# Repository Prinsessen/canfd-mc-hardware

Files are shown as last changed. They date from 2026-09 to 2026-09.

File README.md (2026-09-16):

# CANFD-MC — a minimal CAN board for a motorcycle

A 55 × 32 mm, 4-layer board that replaces the LilyGO T-2CANFD in the
[indian-thunderstroke-canbus](https://github.com/Prinsessen/indian-thunderstroke-canbus)
project: ESP32-S3-WROOM-1U + MCP2518FD + TCAN332G, fed from the bike's
permanent 12 V through an LM5164 buck. Same pin map as the LilyGO board, so the
firmware runs unchanged (`sniffer-t2can` environment).

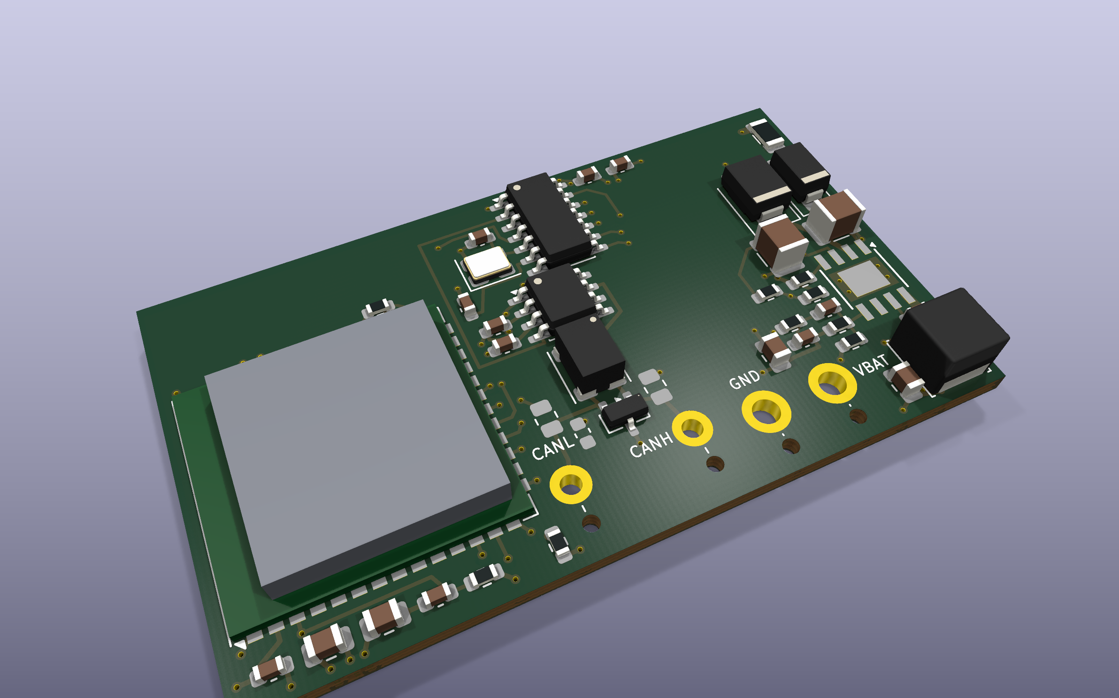
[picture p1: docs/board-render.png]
CANFD-MC rev 1.0, top


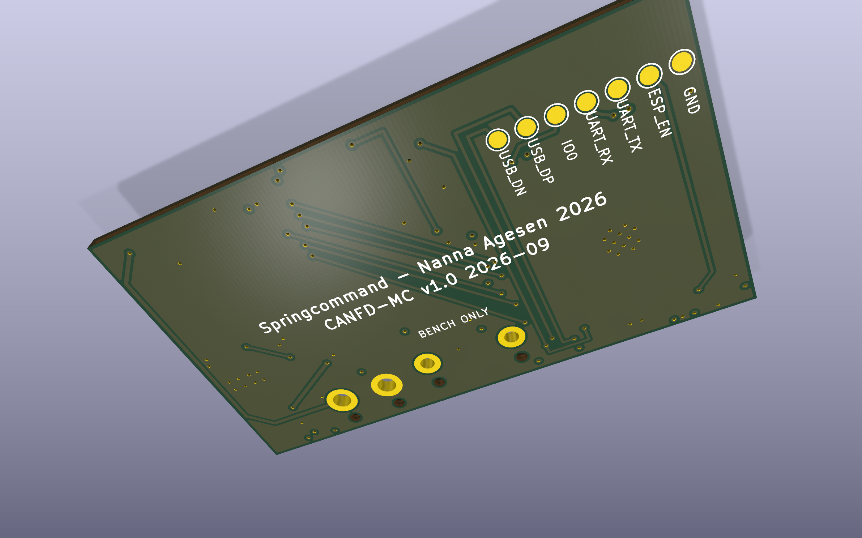
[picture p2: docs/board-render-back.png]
CANFD-MC rev 1.0, back: flash pads, test points, silkscreen


What it drops from the LilyGO board, on purpose: the isolated transceiver (one
machine, one ground — the isolation was bridged the moment it was wired in, and
its DC-DC was three quarters of the sleep current), the USB connector, the screw
terminals, the second CAN channel, and the 120 Ω termination (the bike's bus is
already terminated; a third resistor is a stub). What it adds: a 6–40 V input
that survives load dump, four solder pads with strain-relief holes instead of
connectors, and a ~10 µA regulator so the board can live on the battery.

## Layout

```
canfd-mc.kicad_pro / .kicad_sch / .kicad_pcb   KiCad 10 project — placed, routed, DRC clean
canfd_local.pretty/                            three project footprints (solder pads with relief
                                               holes, Murata DLW43SH with Murata's pin numbering)
production/                                    what JLCPCB was sent: Gerber zip, BOM, CPL
docs/design-document.html                      the full design document: BOM, net list, the
                                               LM5164 calculation, layout rules, checklist
docs/BUILD-NOTES.md                            build, ordering and bring-up notes
docs/WIRING-PARTS.md                           antenna and service-connector cable to order
```

## Connections

Four wires from the service connector, soldered to plated pads along the bottom
edge — **CANL · CANH · GND · VBAT**. Each pad has an unplated 1.2 mm hole 3 mm
inboard: thread the wire up through the hole and down into the pad, so the
board takes the strain instead of the solder joint. No shield pad: the bus
shield is grounded at the ECM.

Flashing pads on the back, 2.54 mm pitch — **GND · EN · TX · RX · IO0 · USB_D+ · USB_D−**.
First flash goes over the ESP32-S3's native USB (a cut USB cable on D+/D−/GND;
the board is powered from 12 V, not from USB). After that, OTA.

## Power input

| | |
|---|---|
| Input | 6–40 V (LM5164 is rated to 100 V; the TVS clamps load dump at ~39 V) |
| UVLO | on at 7.0 V, off at 6.5 V |
| Output | 3.3 V, 300 kHz, 1 A rating (real load < 0.5 A) |
| Protection | 1 A fuse, series Schottky (reverse polarity), SMBJ24CA |

The buck was calculated from the LM5164 datasheet equations and confirmed with
TI's WEBENCH: RON, inductor and bootstrap capacitor came out identical.

## Status

Rev 1.0. Ordered from JLCPCB in September 2026 (5 boards, assembled). Reviewed
([docs/REVIEW-rev1.0.md](docs/REVIEW-rev1.0.md)): net list confirmed against the
datasheets, three notes for rev 1.1. Not yet tested on
hardware — this is a first revision, and the bring-up checklist in the design
document is the plan for finding out what it got wrong.

Things a second revision might change are tracked in the design document's
open-points table.

## Licence

MIT, like the firmware. Design and silkscreen: Springcommand — Nanna Agesen 2026.

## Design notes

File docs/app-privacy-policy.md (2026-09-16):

# Springfield app — privacy policy

*Last updated 16 September 2026*

The Springfield app (package `dk.agesen.springfield`) is an instrument display
for Indian Thunder Stroke motorcycles fitted with the CANFD-MC interface. It is
published by Nanna Agesen, Denmark.

## What the app collects

**Nothing leaves your phone.** The app has no server, no account, no analytics,
no advertising and no crash reporting. It does not connect to the internet.

Data the app handles stays on the device:

- **Motorcycle data** (speed, revs, fuel, tyre pressures, fault codes and so on)
  is received over Bluetooth Low Energy from the interface on the bike and shown
  on screen. Some of it — tyre readings, the trip meter, the service interval —
  is stored on the phone so the app can show trends. It is never transmitted
  anywhere.
- **Heated-clothing control** (Keis) is sent over Bluetooth to your own garment
  controller.

## Permissions

| Permission | Why |
|---|---|
| Bluetooth (scan, connect) | To find and talk to the interface on the bike and to the heated clothing. The scan is declared *never for location*: the app does not derive, store or use your position |
| Foreground service, notifications | To keep the Bluetooth link alive while the screen is off, with a persistent notification while it runs |
| Vibrate | A short tick on a gear change and at the redline |

The app does not request location, camera, microphone, contacts, storage or any
other permission.

## Data sharing

None. No data is shared with the publisher or any third party.

## Deleting your data

Uninstalling the app removes everything it stored. There is nothing to delete
anywhere else.

## Contact

Nanna Agesen — via the GitHub project
[Prinsessen/indian-thunderstroke-canbus](https://github.com/Prinsessen/indian-thunderstroke-canbus).

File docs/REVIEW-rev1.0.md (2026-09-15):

# Review of rev 1.0 — 2026-09-15

A second pair of eyes on the design before the boards arrive, written on the
openHAB server with the firmware repository open beside it. Two parts: what was
checked mechanically, and an opinion on the three design decisions.

## 1. Net list, checked against the datasheets

Checked from `canfd-mc.kicad_pcb` — the pad-to-net assignment that was actually
fabricated — against the firmware's pin map and against Espressif's WROOM-1U
and TI's LM5164 datasheets, not against the design document.

**Everything matches.**

- ESP32 ↔ MCP2518FD is the firmware's map exactly: SCLK 12, MOSI 11, MISO 13,
  CS 10, INT 8. IO9/IO3 are the controller's INT0/INT1 outputs with no pull-ups,
  as on the LilyGO. MCP_INT has a 10 k pull-up, and GPIO8 is RTC-capable, so
  the ext0 wake in `sleep.cpp` works unchanged.
- All 41 module pins agree with the WROOM-1U datasheet, including USB_D− on 13,
  USB_D+ on 14, **RXD0 on 36 and TXD0 on 37** (checked twice; the datasheet
  says pin 36 is U0RXD/GPIO44 and pin 37 is U0TXD/GPIO43).
- LM5164 pin for pin: GND · VIN · EN/UVLO · RON · FB · PGOOD · BST · SW, EP to
  GND. Enable thresholds 1.5 V / 1.4 V and FB reference 1.2 V as used in §4.5.
  The type-3 ripple network is wired as the datasheet draws it: RA from SW to
  the injection node, CA from that node to VOUT, CB from that node to FB.
- Input chain VBAT → F1 → D1 (anode towards the fuse, cathode towards the buck,
  so the right way round) → D2 → C1/C2 → U3.
- Bus front end: TCAN332G → L1 (windings 1–2 and 4–3, Murata's numbering) →
  PESD2CAN on the bus side → pads. RT1/RT2/CT1 unpopulated and marked.
- The strain-relief holes sit between pad and board edge, as §6.0 describes.

## 2. Three things for rev 1.1 — none of them blocks bring-up

1. **The PSRAM open point is cheaper than §2 says.** The firmware is built for
   the PlatformIO board `esp32-s3-devkitc-1`, which is the *"N8, No PSRAM"*
   definition: partition table `default_8MB.csv`, no `BOARD_HAS_PSRAM`. The
   PSRAM is never initialised and only 8 MB of the flash is used. So the
   85 °C variants — **N16R2 or plain N8** — need **no firmware change at all**.
   Open point 7 can be closed as a purchasing decision; I would order rev 1.1
   with an 85 °C module without waiting for the temperature measurement.
2. **Leftover net `ACC_SENSE` on IO1 (pin 39).** One pad, no track, so DRC has
   nothing to complain about. Harmless — IO1 is not a strapping pin — but §4.1
   says IO1 is NC. Delete the label.
3. **BOM comment `22uF 10V`** on C3/C4/C12/C13. LCSC C45783 is Samsung
   CL21A226MAQNNNE: 22 µF **25 V** X5R 0805. The part number drives the order,
   so only the text is wrong.

The firmware side of the §9 checklist — the comment in `can_hal_mcp.cpp` about
Longan_CANFD assuming 40 MHz — is fixed in the firmware repository.

## 3. Opinion on the three decisions

**Yes: the minimal board is the better solution, and each of the three choices
is right for this job.** This is no longer a development board; it is a
permanently installed, single-purpose device on a vehicle that vibrates and
lives off a battery. Those are different requirements from the ones the LilyGO
was built for.

**One channel.** Obvious. The firmware has only ever used CAN A. Channel B was
dead weight, board area and current.

**Solder pads instead of screw terminals.** Right, on a motorcycle. Screw
terminals work loose under vibration, and a solder joint on a vehicle fails at
the root of the wire, not in the solder — which is exactly what the
strain-relief holes address. What you give up is that swapping a board becomes
a soldering job. With five boards and a small service loop in the wires, that
does not matter.

**No galvanic isolation.** Also right, for the reason §1 of the design document
gives: supply and bus come from the same service connector with the same
ground, so the isolation was bridged the moment it was wired in, and its DC/DC
cost three quarters of the sleep current. Isolation protects against ground
offsets between two systems. Here there is one system.

Where the price of those choices actually lies:

- **The one-ground rule has to hold all the way.** The single situation in
  which isolation would have saved something is USB ground to a mains-powered
  PC while the board is on the bike. Bring-up over the USB pads should happen
  with the board off the bike, or with a laptop on battery. Worth a line in
  BUILD-NOTES.
- **The starter motor.** UVLO releases at 6.5 V. A cold crank can dip below
  that. The consequence is a reboot at every start: lost seconds and a BLE
  reconnect. The design document says the wake path tolerates it, and it does.
  But measure the dip during cranking before rev 1.1 is frozen. If it is a
  problem, the answer is a regulator with a lower minimum input, not a bigger
  capacitor.
- **Sleep current.** Without the isolation module, 7–9 mA is expected. That is
  about 0.2 Ah a day — a couple of months of rest on a healthy battery, fine
  for a bike that is ridden. Going lower means the transceiver (the 332G has no
  standby pin) and the MCP2518FD in Normal mode, and that needs a different
  wake strategy. Not now.
- **Temperature.** See item 1 above: an 85 °C module costs nothing in firmware.
- **First-revision risks** are the two the design document already caught: the
  choke footprint with Murata's numbering, and the crystal load capacitors.
  Both are the classic "reads zero frames" faults, and both are handled.

So: not "good enough", but the right design. What is left, only the bench can
answer.

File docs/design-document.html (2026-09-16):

Design document · rev 1.0 · 2026-09-15 · board routed, DRC clean, ordered

# CANFD-MC Adapter

A minimal board for the Indian Springfield bus: ESP32-S3-WROOM-1U + MCP2518FD, soldered wires, no USB connector, no isolation, no termination. The firmware from Prinsessen/indian-thunderstroke-canbus (environment sniffer-t2can) runs unchanged.

MCU module

ESP32-S3-WROOM-1U-N16R8

CAN controller

MCP2518FD · SPI · 40 MHz

Transceiver

TCAN332G · 3.3 V

Supply

6–40 V in · LM5164 → 3.3 V

Bus

J1939 · 250 kbit/s · classic

Board

55 × 32 mm · 4 layers

Pin numbers were looked up in LilyGO's schematic T-2Can-Fd_V1.0.pdf, Espressif's WROOM-1 datasheet and TI SNVSAU4D — not from memory. The buck values in §4.5 were calculated from the datasheet equations and confirmed in WEBENCH.

## 1Block diagram

One ground throughout. Supply and bus come from the same service connector on the bike, so LilyGO's isolated TD501MCANFD module (and its internal DC/DC, which was three quarters of the 17 mA sleep current) is gone. The only parts that are genuinely redrawn compared with LilyGO are the power supply and the bus front end; the MCP2518FD section is a 1:1 copy.

## 2Module choices

ESP32-S3-WROOM-1U-N16R8 — the same module as the T-2CANFD, so platformio.ini (esp32-s3-devkitc-1, 16 MB flash / 8 MB OPI PSRAM) and the partition table are untouched. The module has a U.FL connector instead of a PCB antenna, which is the right choice on a motorcycle anyway.

Temperature: the N16R8 is only rated −40…+65 °C ambient

The 8 MB octal PSRAM is the limit. Under a seat in the sun, 65 °C is not much margin. Review finding (2026-09-15): the firmware is built for the PlatformIO board esp32-s3-devkitc-1, which is the "N8, no PSRAM" definition — the PSRAM is never initialised and only 8 MB of flash is used. So the +85 °C variants N8 or N16R2 need no firmware change. Rev 1.0 was built with the N16R8 before this was noticed; keep those boards out of the hottest spots. Rev 1.1: order an 85 °C module. Same footprint.

MCP2518FD in SOIC-14, 3.3 V, 40 MHz crystal — exactly as LilyGO. The firmware runs the controller in Normal20B (classic CAN + 29-bit IDs) or ListenOnly; CAN FD is not used, but the chip is the one the code and ACAN2517FD know.

TCAN332G — 3.3 V transceiver, SOIC-8, −40…+125 °C, no extra pins to wire. Listen-only is handled in the MCP2518FD, so the transceiver's silent pin (TCAN337G) is unnecessary. Drop-in alternatives with the same base pinout: TCAN337G, SN65HVD230.

LM5164 — 100 V, 1 A synchronous buck with ~10 µA quiescent current. Survives load dump with the TVS as the only protection, and the quiescent current matters when the board hangs permanently on the battery.

## 3BOM

All passives SMD 0603 unless stated. Capacitors X7R (C0G where stated), −55…+125 °C. No electrolytics. LCSC numbers are the parts JLCPCB had in stock on 2026-09-15.

Ref | Part | Value / type | Package | LCSC | Note
Active
U1 | ESP32-S3-WROOM-1U-N16R8 | 16 MB / 8 MB OPI · 65 °C | Module 18 × 19.2 mm | C3013946 | Rev 1.0 as built. Rev 1.1: N8 or N16R2 (85 °C), see §2
U2 | MCP2518FDT-E/SL | CAN FD controller | SOIC-14 | C626758 | As LilyGO
U3 | LM5164DDAR | 100 V / 1 A buck | SO PowerPAD-8 | C477928 | EP to GND plane
U4 | TCAN332GDR | 3.3 V CAN transceiver | SOIC-8 | C191010 | Pins 5 and 8 NC
Oscillator
X1 | Crystal YXC X322540MPB4SI | 40.000 MHz ±10 ppm · CL 15 pF | 3225 | C9010 | −40…+85 °C — the module is the limit anyway. See §4.3
C10, C11 | Load capacitors | 22 pF C0G | 0603 | C1653 | 2·(15 − 3) pF. LilyGO uses 12 pF for a ~10 pF crystal — not the same crystal
Supply — input
P1, P2 | Solder pad VBAT / GND | Ø2.0 mm plated | — | — | + strain-relief hole, §6.0
F1 | Fuse 1 A slow | 63 V | 1206 | C151135 | Littelfuse 0466001.NRHF
D1 | Schottky, series (reverse polarity) | SS36 · 60 V / 3 A | SMA | C16015 | ~0.35 V drop, ~40 mW at 100 mA
D2 | TVS, bidirectional | SMBJ24CA | SMB | C83268 | After D1. Clamps load dump < 40 V. Bidirectional = cannot be placed backwards
C1, C2 | Input capacitor | 4.7 µF 100 V X7S | 1210 | C385986 | As close as possible to U3 VIN/GND
Supply — LM5164 (calculated in §4.5)
L2 | Inductor, shielded | 22 µH · Changjiang FNR5040S220MT | 5 × 5 × 4 mm | C167971 | Isat ~1.7 A — plenty for a real load < 0.5 A
C3, C4 | Output capacitor | 22 µF 25 V X5R | 0805 | C45783
C5 | Bootstrap | 2.2 nF 50 V X7R | 0603 | C1604 | Datasheet requirement
R1 | RRON | 27.4 kΩ 1 % | 0603 | C22964 | → 300 kHz
R2 | RFB1 (VOUT → FB) | 100 kΩ 1 % | 0603 | C25803
R3 | RFB2 (FB → GND) | 57.6 kΩ 1 % | 0603 | C23082 | → 3.28 V
R4 | RA (SW → CA) | 150 kΩ | 0603 | C22807 | Type-3 ripple injection
C6 | CA | 2.2 nF X7R | 0603 | C1604 | Type-3 ripple injection
C7 | CB | 270 pF C0G | 0603 | C1657 | Type-3 ripple injection
R5 | RUV1 (VIN → EN) | 365 kΩ 1 % | 0603 | C23031 | UVLO on 7.0 V / off 6.5 V
R6 | RUV2 (EN → GND) | 100 kΩ 1 % | 0603 | C25803
Decoupling 3V3
C12, C13 | ESP32 bulk | 22 µF 25 V X5R | 0805 | C45783 | At U1 pin 2 — as LilyGO C4/C5
C14 | ESP32 HF | 100 nF | 0603 | C14663 | At U1 pin 2
C15, C16 | MCP2518FD | 10 µF + 100 nF | 0603 | C19702 · C14663 | At U2 pin 14 — as LilyGO C13/C12
C17, C18 | TCAN332G | 4.7 µF + 100 nF | 0603 | C19666 · C14663 | At U4 pin 3
C19 | EN delay | 1 µF | 0603 | C15849 | U1 EN → GND (LilyGO C8)
R7, R8, R9 | Pull-up EN · IO0 · INT | 10 kΩ | 0603 | C25804 | To 3V3
Bus front end
P3, P4 | Solder pad CANH / CANL | Ø1.5 mm plated | — | — | + strain-relief hole, §6.0
L1 | Common-mode choke, CAN | Murata DLW43SH101XK2L | 4532 | C123085 | AEC-Q200. Pins 1/4 at one end, 2/3 at the other — project footprint. Does not tolerate hard potting (§6)
D3 | TVS, CAN | Nexperia PESD2CAN | SOT-23 | C75176 | Pins 1/2 to CANH/CANL, pin 3 GND — on the bus side of L1
RT1, RT2 | Split termination | 60.4 Ω | 0805 | — | DO NOT POPULATE §4.4
CT1 | Split termination, centre | 4.7 nF | 0603 | — | DO NOT POPULATE §4.4
Test / flash
TP1–TP7 | Pogo pads Ø1.5 mm, 2.54 mm pitch, back side | GND · EN · TX · RX · IO0 · USB D+ · USB D− | — | — | Nothing mounted. First flash only; OTA after that

## 4Net list

### 4.1ESP32-S3-WROOM-1U — pins used

Numbering per Espressif's WROOM-1/1U datasheet; confirmed against LilyGO's symbol. All other pins are NC.

Pin | Name | Net | Connects to | Note
1, 40, 41 | GND, GND, EP | GND | GND plane | EP: via array
2 | 3V3 | 3V3 | C12, C13, C14
3 | EN | ESP_EN | R7 10k → 3V3, C19 1 µF → GND, TP5
27 | IO0 | IO0 | R8 10k → 3V3, TP4 | Boot strap
12 | IO8 | MCP_INT | U2 pin 4, R9 10k → 3V3 | RTC GPIO → ext0 wake in sleep.cpp
18 | IO10 | SPI_CS | U2 pin 13 | MCP_CS
19 | IO11 | SPI_MOSI | U2 pin 11 (SDI) | MCP_MOSI
20 | IO12 | SPI_SCLK | U2 pin 10 (SCK) | MCP_SCK
21 | IO13 | SPI_MISO | U2 pin 12 (SDO) | MCP_MISO
17 | IO9 | MCP_INT0 | U2 pin 9 | As LilyGO. Controller output — the ESP must never drive it
15 | IO3 | MCP_INT1 | U2 pin 8 | As LilyGO. Same rule
13 | IO19 | USB_DN | TP2 | Native USB-Serial/JTAG — matches ARDUINO_USB_CDC_ON_BOOT=1
14 | IO20 | USB_DP | TP3
37 | TXD0 | UART_TX | TP6 | Backup flash path
36 | RXD0 | UART_RX | TP7
28, 29, 30 | IO35, IO36, IO37 | — | NC | Used internally by the OPI PSRAM — must not be used
26, 16 | IO45, IO46 | — | NC | Strap pins; internal pull-downs

### 4.2MCP2518FD (SOIC-14) and TCAN332G (SOIC-8)

U2 pin | Name | Net / connection
1 | TXCAN | → U4 pin 1 (TXD)
2 | RXCAN | ← U4 pin 4 (RXD)
3 | CLKO/SOF | NC
4 | INT# | MCP_INT → U1 IO8, R9 pull-up
5 | OSC2 | X1 + C11 22 pF → GND
6 | OSC1 | X1 + C10 22 pF → GND
7 | VSS | GND
8 | INT1#/GPIO1 | MCP_INT1 → U1 IO3
9 | INT0#/GPIO0/XSTBY | MCP_INT0 → U1 IO9
10 | SCK | SPI_SCLK ← U1 IO12
11 | SDI | SPI_MOSI ← U1 IO11
12 | SDO | SPI_MISO → U1 IO13
13 | nCS | SPI_CS ← U1 IO10
14 | VDD | 3V3 + C15 10 µF + C16 100 nF

U4 pin | Name | Net / connection
1 | TXD | ← U2 pin 1
2 | GND | GND
3 | VCC | 3V3 + C17 4.7 µF + C18 100 nF
4 | RXD | → U2 pin 2
5 | NC | — (FAULT on the TCAN337G)
6 | CANL | → L1 → D3 → RT2 (DNP) → P4
7 | CANH | → L1 → D3 → RT1 (DNP) → P3
8 | NC | — (S on the TCAN337G; tie to GND if a 337G is fitted)

No RESET line: the MCP2518FD has no reset pin, and ACAN2517FD resets it over SPI in begin(). IO9/IO3 are the controller's outputs — that is exactly the contention can_hal_mcp.cpp warns about, so they are wired as on LilyGO and never touched in firmware.

### 4.3Oscillator: 40 MHz crystal — settled by your own firmware

- 40 MHz, not 20. can_hal_mcp.cpp sets MCP_OSC_HZ 40000000UL and ACAN2517FDSettings::OSC_40MHz. ACAN2517FD derives its bit timing from that frequency; had the crystal been 20 MHz, 250 kbit/s would have been configured as 125, and you would read zero frames. You read frames (live J1939 from the Zealand ride, version 2026.09.14-x). Running firmware beats vendor examples.
- LilyGO's own can example is a trap. It calls begin() without a clock argument, and Longan_CANFD defaults to 20 MHz — so the example cannot work on their own board. LilyGO's wiki itself notes that it "requires CAN FD adaptation".
- It is a crystal, not an oscillator module. LilyGO's schematic shows X1 "40MHZ ±10ppm" on OSC1/OSC2 with C16/C17 = 12 pF; the MCP2518FD's internal Pierce oscillator drives it. Cheaper and more vibration-tolerant than an active module. LilyGO's 2 × 12 pF suit a crystal with CL ≈ 9–10 pF; the crystal JLCPCB stocks (X322540MPB4SI) has CL = 15 pF, so here C10/C11 = 22 pF: C = 2·(CL − Cstray) = 2·(15 − 3).

Small correction for your repo

The comment in can_hal_mcp.cpp line 17 says "Longan_CANFD + ACAN2517FD both assume 40 MHz here". That is only true of ACAN2517FD — Longan defaults to 20. The conclusion is right; the premise can send the next reader the wrong way.

### 4.4Termination: DO NOT POPULATE

The bike's bus already has its 2 × 120 Ω, and the board sits on a stub. A third termination would pull the bus down to 40 Ω and cause reflections. RT1/RT2/CT1 stay as empty footprints marked BENCH ONLY on the silkscreen — they exist only for the day the board sits on the bench against a USB-CAN adapter without a real bus, when both ends need terminating.

What you actually need to watch is the stub length. At 250 kbit/s you have about a metre from the tap point to the board before reflections start to cost. Keep it short, and keep the twist of the CAN pair right up to P3/P4.

### 4.5LM5164 — calculated values CONFIRMED IN WEBENCH

Calculated from TI SNVSAU4D (rev. Feb 2026), section 7.2.2 and table 6-1. Assumptions: VOUT = 3.3 V, VIN nominal 13.8 V, VIN 6–40 V, IOUT dimensioned for 1 A (actual < 0.5 A — WiFi TX bursts dominate).

Switching frequency

300 kHz → RRON = 27.4 kΩ

RRON [kΩ] = VOUT · 2500 / FSW [kHz] = 3.3·2500/300 = 27.5 (eq. 15). The 50 ns minimum on-time gives VIN,max = 3.3/(50 ns·300 kHz) = 220 V — no constraint.

Inductor

22 µH

L = VOUT/(FSW·ΔIL)·(1−VOUT/VIN) with ΔIL = 0.4 A at 13.8 V → 20.9 µH (eq. 20). At 40 V: ΔIL = 0.46 A. Ipeak ≈ 1.2 A at 1 A load → Isat ≥ 1.5 A.

Output capacitor

2 × 22 µF

COUT ≥ ΔIL/(8·FSW·ΔVOUT) = 0.4/(8·300k·16.5 mV) ≈ 10 µF (eq. 21). Doubled for DC-bias derating.

Feedback divider

RFB1 100 kΩ · RFB2 57.6 kΩ

RFB2 = 1.2 V/(VOUT−1.2 V)·RFB1 = 57.1 kΩ (eq. 10). E96: 57.6 kΩ → VOUT = 1.2·(1+100/57.6) = 3.283 V.

Ripple injection, type 3

RA 150 kΩ · CA 2.2 nF · CB 270 pF

CA ≥ 10/(FSW·RFB1∥RFB2) = 0.91 nF (eq. 24). RA·CA ≤ tON·(VIN−VOUT)/20 mV; tON = 797 ns at 13.8 V → gives 25 mV at 13.8 V, 15 mV at 6 V (min. 12 mV ✓), 31 mV at 40 V. CB ≥ 75 µs/(3·RFB1) = 250 pF (eq. 26), C0G.

UVLO

RUV1 365 kΩ · RUV2 100 kΩ

VIN,on = 1.5·(1+RUV1/RUV2) = 6.98 V; VIN,off = 1.4·(1+…) = 6.51 V (eq. 13/14). Below 6 V the LM5164 is out of spec anyway. During a cranking dip the board restarts — the wake path is already robust to that.

Input

2 × 4.7 µF 100 V + CBST 2.2 nF

Datasheet: ≥ 2.2 µF HF ceramic, voltage rating ≥ 2 × VIN,max. The battery leads are > 5 cm, so D2 + ceramics sit right at U3.

Sleep current, expected

≈ 7–9 mA from 12 V

MCP2518FD in Normal (~10–20 mA) + TCAN332G recessive (~6 mA) at 3.3 V, LM5164 ~10 µA. Through the buck ≈ half of the 17 mA measured on the LilyGO — the isolated DC/DC is gone. Measure it.

WEBENCH run 2026-09-15 (VIN 6–40 V, VOUT 3.3 V, IOUT 1 A, 60 °C): TI's tool picks RON 27.4 kΩ, L 22 µH and CBST 2.2 nF — identical to the above. Feedback 178k/101k (same ratio as 100k/57.6k), Cout 3 × 10 µF, ripple network 205k/1.2 nF/100 pF — equivalent to ours, which injects slightly less ripple and still ≥ 12 mV at 6 V. Efficiency 78 % at 1 A.

Type 3 was chosen because the output is pure ceramic with no ESR — types 1/2 would need a series resistor and more ripple on 3V3.

## 5Layout

### 5.1Stackup — 4 layers, 1.6 mm (JLC04161H-7628)

Layer | Content
L1 top | All components, power loop, crystal, CAN front end, decoupling, CAN RX
L2 (In1) | Unbroken GND plane
L3 (In2) | 3V3 plane (+ one short trace for the unpopulated termination centre)
L4 bottom | SPI + INT (6 traces U1 ↔ U2), CAN TX, MCP_INT, USB/UART/IO0/EN to the flash pads, VBAT along the right edge, GND fill, silkscreen (§6.1)

### 5.2Placement (as built)

1. U1 at the left end, U.FL connector facing out over the board edge. The WROOM-1U has no PCB antenna, so there is no keep-out beyond the module's own edge — but the buck and its inductor are kept away from it.
2. U3 + L2 + C1/C2 + C3/C4 at the right end. The hot loop (C1 → U3 VIN → SW → L2 → C4 → GND) is the smallest area on the board. SW node: only on L1, short and wide.
3. U2 and X1 top centre. Crystal within 5 mm of OSC1/OSC2, C10/C11 between crystal and U2, GND return straight to pin 7.
4. U4 → L1 → D3 → pads in a straight line down the middle. D3 on the bus side of L1, closest to the pads.
5. SPI on the back, ≤ 25 mm, over unbroken GND.

### 5.3The seven rules

1. CANH/CANL routed as a pair, 0.3 mm trace, matched length, no vias between U4 and the pads.
2. Decoupling capacitors within 2 mm of the pin they decouple; 100 nF closest.
3. U3's EP and U1's EP: via arrays into L2.
4. FB node (R2/R3/C7) short and away from SW and L2. The RA/CA branch may run along SW — it is meant to see SW.
5. VBAT path from P1 through F1 → D1 → D2/C1 → U3: 0.8 mm wide on top, 0.4 mm on the back run. 3V3 plane on L3.
6. Signal name at every solder pad on the silkscreen. CANH/CANL can be swapped with solder pads — they could not with a keyed connector.
7. No component closer than 1.5 mm to the board edge (coating and edge milling).

## 6Mechanical and environment

- All SMD, no pin headers, no electrolytics, no screw terminals.
- −40/+105 °C parts; AEC-Q200 passives where they cost nothing extra. The exception is U1 (§2).
- Conformal coating after the first flash and test — or soft silicone potting. Not epoxy: Murata's spec for L1 (§13.4) warns that cure stress from resin can change the inductance or break the wire; the same caution applies to X1. Keep the U.FL connector and the pads free during testing.
- No mounting holes: the board is coated or potted, and fixed with foam tape and a cable tie, or potted in a small box.
- Antenna: the diymore 2.4G 5dBi FPC flex antenna with U.FL (the one LilyGO ships, proven on the bike), stuck to the inside of a plastic cover, clear of metal and carbon fibre. Wiring to the bike: a moulded Polaris/Indian 8-way GT 150 adapter plug. Both in WIRING-PARTS.md.

### 6.0Soldered wires — pads, no connectors

The service connector provides CAN H, CAN L, GND and permanent 12 V. Because the board is not isolated there is one ground: LilyGO's five wires (12 V+, 12 V−, D GND, CAN H, CAN L) become four — VBAT, GND, CANH, CANL — along the bottom edge.

Pad | Signal | Wire from the service connector | Hole
P4 | CANL | C02-2 DG | Ø1.5 mm
P3 | CANH | C02-1 YE | Ø1.5 mm
P2 | GND | GND — one wire, shared by supply and bus | Ø2.0 mm
P1 | VBAT (permanent 12 V) | 12 V+ | Ø2.0 mm

Strain-relief holes — the difference between lasting a season and lasting years

A solder joint on a vibrating vehicle breaks at the root of the wire, not in the solder. The fix costs nothing: an extra Ø1.2 mm unplated hole 3 mm from each pad. The wire comes in from the edge, up through the hole, and down into the pad, so the board takes the strain instead of the joint. Add a drop of glue or resin over each pad after soldering.

The CAN shield is not bonded on the board — it is already grounded at the ECM (single point). So there is no S GND pad.

### 6.1Silkscreen

Bottom side (L4), 1.2 mm text height, 0.2 mm stroke, with no components under it:

Springcommand - Nanna Agesen 2026
CANFD-MC v1.0 2026-09

- Plain ASCII hyphen, not an en dash — several fabs' Gerber fonts lack the glyph and silently drop it.
- The revision line is worth its weight the day three versions sit in a drawer.
- Top side: signal name at every pad. Back side: BENCH ONLY under RT1/RT2, and the flash-pad names.

## 7Open points

Point | Status | What it takes
Connector choice | CLOSED | Solder pads with strain relief, §6.0
Permanent vs. ignition-switched supply | CLOSED | Permanent 12 V, as today. The ACC wake input considered in SLEEP.md was dropped: the firmware wakes on CAN (ext0 on GPIO 8) and needs nothing else
Does the firmware use FD frames? | CLOSED | No — Normal20B, classic J1939 at 250 kbit/s. The hardware can do FD; it is not used
Oscillator frequency | CLOSED | 40 MHz crystal, §4.3
LM5164 RON / inductor / feedback | CLOSED | Confirmed in WEBENCH 2026-09-15 — RON, L and CBST identical to TI's choice, §4.5
Crystal part number | CLOSED | YXC X322540MPB4SI (CL 15 pF) + 2 × 22 pF — what JLCPCB stocks. Standard 3225 pinout (1/3 crystal, 2/4 GND)
Module variant (temperature) | CLOSED | Firmware does not use PSRAM (board esp32-s3-devkitc-1 = N8 definition). Rev 1.1: N8 or N16R2, 85 °C, no firmware change

### 7.1Notes for rev 1.1

From the review of rev 1.0. None of these blocks bring-up of rev 1.0.

- Module: N8 or N16R2 (85 °C) instead of N16R8. No firmware change.
- Leftover ACC_SENSE label on IO1 — removed in the repository after the order; the fabricated rev 1.0 has an unconnected pad there, which is harmless.
- BOM text for C3/C4/C12/C13 said 10 V; the ordered part (C45783) is 25 V. Text corrected.
- Cranking dip: UVLO releases at 6.5 V; a cold crank can dip below that and reboot the board (the wake path tolerates it). Measure the dip during cranking before rev 1.1 is frozen. If it matters, the fix is a regulator with a lower minimum input, not a bigger capacitor.
- One-ground rule: flashing over the USB pads must happen with the board off the bike, or from a laptop on battery — a mains-powered PC's USB ground to the bike's ground is the one case the dropped isolation would have covered.

Candidate board changes for rev 1.1 — none justify a new order on their own; take them along when the bench gives a reason:

- Test pads for +3V3 and VIN_PROT on the back, next to the flash pads — measuring on 0603 capacitor pads is a poor way to debug on a bike.
- RT1/RT2 as 1206 with more room around them: they are fitted and removed by hand for bench testing.
- An unpopulated 1.27 mm header footprint (or wider pads) in place of the pogo pads, so a header can be press-fitted for the first flash without a fixture.
- If the cranking measurement shows reboots: a regulator with a lower minimum input (LM5163 / LM61460 class) or a lower UVLO — a schematic change, so wait for the measurement.

## 8Sources

- LilyGO T-2Can repo — libraries/private_library/pin_config.h and project/T-2Can-Fd_V1.0.pdf (schematic: MCP2518FD pinout, X1 40 MHz + 2×12 pF, INT/INT0/INT1 → IO8/IO9/IO3, RS2 10k pull-up). github.com/Xinyuan-LilyGO/T-2Can
- Prinsessen/indian-thunderstroke-canbus — firmware/src/can_hal_mcp.cpp (pin map, OSC_40MHz, no reset), sleep.cpp/docs/SLEEP.md (ext0 on IO8, 17 mA measurement, wiring), docs/FLASHING.md (wire colours, shield not bonded), platformio.ini (sniffer-t2can, USB CDC). github.com/Prinsessen/indian-thunderstroke-canbus
- TI LM5164 datasheet SNVSAU4D, rev. Feb 2026 — pin functions (table 4-1), eq. 10, 13–26, table 6-1. WEBENCH Power Designer, run 2026-09-15.
- Espressif ESP32-S3-WROOM-1/1U datasheet — pinout, temperature grades (OPI-PSRAM variants −40…65 °C).
- Microchip MCP2518FD datasheet — SOIC-14 pinout, crystal on OSC1/OSC2.
- TI TCAN33x datasheet — SOIC-8 pinout, 3.3 V operation, interoperability with 5 V nodes.
- Murata DLW43SH spec JEFL243C — pin arrangement (1/4 one end, 2/3 the other), resin-coating caution §13.4.

## 9Checklist before fab

- WEBENCH run of §4.5 — done, RON/L/CBST identical to TI's choice
- X1 footprint matches the purchased part (3225, pad orientation) — done
- ERC/DRC clean; IO35/36/37 are NC; IO9/IO3 are inputs without pull-ups — done
- RT1/RT2/CT1 marked DNP in the BOM and "BENCH ONLY" on the silkscreen — done
- Strain-relief holes at P1–P4, Ø1.2 mm, unplated, 3 mm from the pad — done
- Silkscreen: ASCII hyphen, 1.2 mm height, bottom side free of components — done
- GND plane on In1 unbroken under SW node, crystal and CAN pair — done
- After assembly: 60 Ω bench check of the bike's bus before the board is connected (as in FLASHING.md)
- First flash via the USB_DP/USB_DN pads on the back, board powered from a current-limited 12 V bench supply; OTA after that
- Measure sleep current in series with 12 V, compare with the 17 mA baseline in SLEEP.md
- Fix the comment in can_hal_mcp.cpp line 17 (Longan defaults to 20 MHz)

## 10KiCad project and ordering

The document was turned into a KiCad 10 project, and the board is placed and routed: DRC 0 errors, 0 unconnected (55 × 32 mm, 4 layers, 193 track segments, 68 vias). The production files are in the repository's production/ folder: Gerber zip, BOM (26 lines, all with LCSC numbers, DNP parts omitted) and placement file (CPL) in JLCPCB's format. All four main ICs were verified in stock at JLCPCB on 2026-09-15.

Step | What | Status
1 | WEBENCH run of §4.5 | Done 2026-09-15 — confirmed
2 | JLCPCB order: 4 layers, FR4 TG135, LeadFree HASL, 0.3 mm vias, 5 boards | Ordered September 2026
3 | Standard PCBA top side, 5 boards, Confirm Parts Placement | Ordered. Check pin 1 of U1–U4, D1, D3, L1 on the engineer's confirmation image before approving

Every calculation in the document is now backed by a datasheet or a simulation. What remains is the part no document can do: the bring-up on the bench.

CANFD-MC Adapter · rev 1.0 · Springcommand · Nanna Agesen · 2026-09-15. All corrections from the original thread (40 MHz, solder pads, no termination, silkscreen) are incorporated.

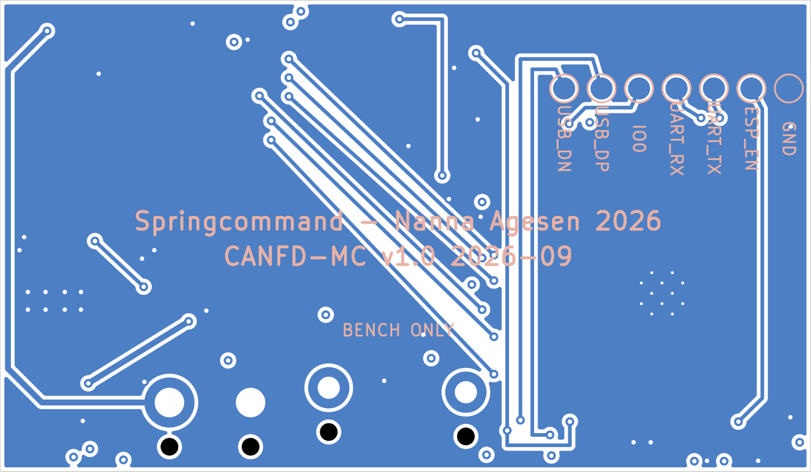
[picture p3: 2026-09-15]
docs/board-bottom.png

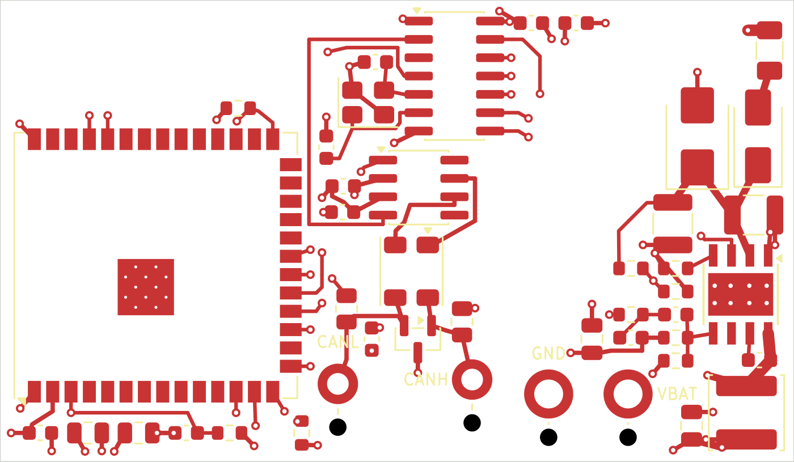
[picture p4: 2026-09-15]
docs/board-top.png

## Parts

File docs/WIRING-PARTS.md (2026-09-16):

# Wiring parts — antenna and service-connector cable

The two things the board needs that JLCPCB does not supply. Both are cheap; order
them with the boards so they arrive together.

## Antenna

**diymore 2.4G 5dBi FPC antenna, IPEX/U.FL, 50 Ω** —
[AliExpress 32997757781](https://www.aliexpress.com/item/32997757781.html).
The same flex antenna LilyGO ships with the T-2CANFD, and it has worked on the
bike since day one, so it is the known-good choice. ~US $0.35 each; buy five —
U.FL connectors are rated for about 30 mating cycles and the price is the same.

What to check on any substitute: connector **IPEX1 / U.FL / MHF1** (not MHF4),
2.4 GHz, 1.13 mm cable, 10–15 cm. Mount the flex on the inside of a plastic
cover, clear of steel and carbon fibre. Once the plug is seated, a drop of hot
glue or a piece of Kapton tape over the U.FL connector — it works loose under
vibration otherwise.

## Service connector (DIAG, C02)

The bike's diagnostic connector is an **Aptiv (Delphi) GT 150, 8-way**, male
header on the bike (Delphi 15326840). It is the same connector Polaris uses on
its ATVs, RZR and Slingshot — Indian is Polaris — so the cheap "Polaris OBD2
adapter" cables fit.

Pinout at the bike, from the firmware repo's FLASHING.md (cavities H G F E D C B A):

| Cavity | Wire | Signal | Board pad |
|---|---|---|---|
| H | C02-1 YE | CAN H | CANH |
| G | C02-2 DG | CAN L | CANL |
| F / E | GND3-03 BK | Ground | GND |
| (one more) | — | Permanent battery 12 V | VBAT — **identify with a meter before soldering** |

Do not connect the CAN shield; it is grounded at the ECM.

### Easiest: a ready-made adapter cable, OBD2 end cut off

**"OBD2 to 8 pin diagnostic adapter for Polaris ATV / Slingshot"** —
[AliExpress 1005004883918813](https://www.aliexpress.com/item/1005004883918813.html)
(also many eBay listings, "16 pin female to 8 pin OBD2 Polaris"). A moulded,
sealed GT 150 8-way plug with a 30–50 cm cable to an OBD2 socket, ~US $5–10.

Cut the OBD2 socket off and you have a sealed plug with exactly the wires the
board needs. Identify them with a meter against the OBD2 socket **before**
cutting: OBD2 pin 6 = CAN H, pin 14 = CAN L, pin 4/5 = ground, pin 16 = battery
12 V. Wire gauge is 22–20 AWG, plenty for < 200 mA. Leave a service loop.

An alternative with the same result: the official Indian OBD adapter harness,
part 2414868 — more expensive, same connector.

### If you would rather crimp your own

Aptiv GT 150 8-way sealed female housing **15326835** (black) or 15326839
(grey), with GT 150 female terminals and cable seals for 0.5–0.75 mm² wire, plus
the TPA lock. Kits with housing, terminals and seals are on AliExpress
("Delphi GT series 8 pin 15326835") for under US $1, and from Mouser, Waytek
or EFI Connection. Needs a proper open-barrel crimp tool — a pair of pliers does
not make a vibration-proof crimp. The adapter cable above avoids all of this.

### Bench check before connecting the board

Ignition off, measure across CAN H and CAN L at the plug: **about 60 Ω** (the
bus's two 120 Ω terminators in parallel). Open circuit means wrong pins.

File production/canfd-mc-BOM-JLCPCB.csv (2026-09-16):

Comment | Designator | Footprint | LCSC Part #
4.7uF 100V X7R | C1,C2 | C_1210_3225Metric | C385986
22uF 25V | C3,C4,C12,C13 | C_0805_2012Metric | C45783
2.2nF 50V | C5,C6 | C_0603_1608Metric | C1604
270pF C0G | C7 | C_0603_1608Metric | C1657
22pF C0G | C10,C11 | C_0603_1608Metric | C1653
100nF | C14,C16,C18 | C_0603_1608Metric | C14663
10uF | C15 | C_0603_1608Metric | C19702
4.7uF | C17 | C_0603_1608Metric | C19666
1uF | C19 | C_0603_1608Metric | C15849
SS36 | D1 | D_SMA | C16015
SMBJ24CA | D2 | D_SMB | C83268
PESD2CAN | D3 | SOT-23 | C75176
1A 63V | F1 | Fuse_1206_3216Metric | C151135
DLW43SH101XK2L | L1 | L_CommonModeChoke_Murata_DLW43SH | C123085
22uH | L2 | L_Changjiang_FNR5040S | C167971
27.4k | R1 | R_0603_1608Metric | C22964
100k | R2,R6 | R_0603_1608Metric | C25803
57.6k | R3 | R_0603_1608Metric | C23082
150k | R4 | R_0603_1608Metric | C22807
365k | R5 | R_0603_1608Metric | C23031
10k | R7,R8,R9 | R_0603_1608Metric | C25804
ESP32-S3-WROOM-1U-N16R8 | U1 | ESP32-S3-WROOM-1U | C3013946
MCP2518FDT-E/SL | U2 | SOIC-14_3.9x8.7mm_P1.27mm | C626758
LM5164DDAR | U3 | TI_SO-PowerPAD-8_ThermalVias | C477928
TCAN332GDR | U4 | SOIC-8_3.9x4.9mm_P1.27mm | C191010
40MHz 15pF | X1 | Crystal_SMD_3225-4Pin_3.2x2.5mm | C9010

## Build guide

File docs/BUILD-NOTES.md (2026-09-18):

# Build notes — CANFD-MC rev 1.0

What is in the repository, how to regenerate the production files, how the
board was ordered, and how to bring it up. The design itself — BOM, net list,
the LM5164 calculation, layout rules — is in
[design-document.html](design-document.html).

## Files

| File | What |
|---|---|
| `canfd-mc.kicad_pro` | The project — open this one. Design rules and net classes (Default / Power / CAN) are set for JLCPCB 4-layer |
| `canfd-mc.kicad_sch` | Schematic. Every connection is a local label, grouped in five rows. Symbols are embedded, so it opens without library errors |
| `canfd-mc.kicad_pcb` | Board: 55 × 32 mm, 4 layers, stackup ≈ JLC04161H-7628, placed and routed, DRC clean |
| `canfd_local.pretty/` | Three project footprints: solder pads with a strain-relief hole (Ø2.0 and Ø1.5) and the Murata DLW43SH with Murata's pin numbering (KiCad's built-in 4532 choke footprint uses TDK's numbering, which would short the windings) |
| `fp-lib-table` | Registers `canfd_local` for the project |
| `production/canfd-mc-gerber.zip` | Upload as the PCB file: 4 copper layers, mask, paste, silkscreen, outline, PTH + NPTH drill files |
| `production/canfd-mc-BOM-JLCPCB.csv` | BOM for assembly — 26 lines, 37 parts, all with LCSC numbers. RT1/RT2/CT1 (do not populate) are omitted |
| `production/canfd-mc-CPL-JLCPCB.csv` | Placement file — 37 parts, top side |

Routing: power loop, crystal and CAN chain on top; SPI/INT, CAN TX, MCP_INT,
flash pads and VBAT on the back; GND plane on In1, 3V3 plane on In2, GND fill on
the back. Flash pads on the back, left to right: GND · EN · TX · RX · IO0 ·
USB_D+ · USB_D− (2.54 mm pitch, names on the silkscreen).

## Regenerating the production files

Edit in KiCad, run DRC (`Inspect ▸ Design Rules Checker`), then
`File ▸ Fabrication Outputs ▸ Gerbers` (all copper layers, F/B.Silkscreen,
F/B.Mask, F.Paste, Edge.Cuts; tick *Generate Drill Files*) and
`File ▸ Fabrication Outputs ▸ Component Placement` (CSV, mm, top). The BOM
comes from `File ▸ Export ▸ Bill of Materials` with the `LCSC` field. The same
can be done from the command line with `kicad-cli`.

Board Setup → Constraints must have *Minimum drill size* at 0.3 mm — the ESP32
module's thermal vias were enlarged from the library's 0.2 mm so the board can
be made with JLCPCB's standard via option.

## Ordering at JLCPCB (as done for rev 1.0)

- Upload `canfd-mc-gerber.zip`. Detected automatically: 4 layers, 55 × 32 mm.
- **PCB:** FR4 TG135 · 1.6 mm · LeadFree HASL · 1 oz outer / 0.5 oz inner ·
  min via 0.3 mm/(0.4/0.45 mm) · via covering as offered (Plugged on 4-layer) ·
  *Confirm Production File: Yes* · *Mark on PCB: Remove Mark*.
  Do not pick the 0.2 mm via option — it silently adds a 4-wire Kelvin test and
  a TG155 laminate.
- **Assembly:** *Standard* PCBA (the ESP32 module is "Standard only"), top side,
  edge rails added by JLCPCB (Standard needs ≥ 70 mm per side; the rails are
  V-scored and snap off), *Confirm Parts Placement: Yes*.
  Leave *Conformal Coating* off — it would coat the flash pads, the solder pads
  and the U.FL connector, all of which you need bare until after bring-up.
- **Parts:** all 26 lines match on LCSC. If something is out of stock, take the
  suggested substitute for passives, not for U1–U4, X1, L1, L2.
- **Placement:** JLCPCB's zero-rotation is defined per part in *their* library,
  not per package, so the CPL rotations KiCad exports do not match theirs for
  several parts. Their engineer corrects this and then asks for a *Confirm
  Parts Placement*. Expect it; it is not a fault in the layout. See the
  checklist below for what to verify before clicking Yes.

### Placement confirmation checklist (verified for rev 1.0, 2026-09-18)

The layout is the reference — every item below was checked pad-for-pad against
`canfd-mc.kicad_pcb` and JLCPCB's corrected placement matched it. Only these
six parts have an orientation that can be wrong; everything else is symmetric.

| Part | Correct orientation on the board | How to see it in JLCPCB's viewer |
|---|---|---|
| U1 ESP32-S3-WROOM-1U | U.FL connector towards the **left** board edge; pads along top, right, bottom | Round U.FL in the top-left corner of the module |
| U2 MCP2518FD (SOIC-14) | Pin 1 **top-left**, body vertical | Pin-1 dot next to the silkscreen triangle, nearest X1 |
| U4 TCAN332 (SOIC-8) | Pin 1 **top-left**, body vertical, below U2 | Pin-1 dot towards U2 |
| U3 LM5164 (SOIC-8 PowerPAD) | Pin 1 **top-right**; pins 1–4 (GND/VIN/EN/RON) towards C1/D2, pins 5–8 towards L2 | Pin-1 dot in the top-right corner |
| D1 SS36 (SMA) | **Anode (+) towards F1 at the top, cathode towards C1/U3 at the bottom** — pad 1 = cathode = VIN_PROT at the lower pad | Their symbol: "+" at the top, diode bar at the bottom |
| D3 PESD2CAN (SOT-23) | **One pin down** towards the CANH/CANL pads (pin 3, GND), two pins up towards L1 | Pins 1 and 2 are interchangeable (both CAN lines) |

Cannot be wrong by construction: D2 (bidirectional TVS), L1/L2/X1/F1 and all
R/C (symmetric). If anything in the table does not match, use the viewer's
rotate button on that part (or answer *No, modification needed* and say which
part), never change the KiCad file to match JLCPCB.
- Shipping DDP if offered — the value is above the EU 150 € threshold, and DDP
  avoids the courier's import-handling fee at the door.

## Bring-up

1. Bench supply, 12 V, **current-limited to 100 mA** for the first power-up.
   Check 3.3 V on C3/C4, note the quiescent current.
2. First flash over native USB — **board off the bike, or laptop on battery**
   (see rev 1.1 notes): a USB cable with the device end cut off —
   green D+ → `USB_DP`, white D− → `USB_DN`, black → `GND`, red not connected.
   Pogo pins or three temporary wires on the back-side pads. The ESP32-S3
   enumerates as a USB JTAG/serial port; `pio run -e sniffer-t2can -t upload`.
   If it will not enter the bootloader on its own: hold `IO0` low, pulse `EN`
   low, release `IO0`. A 3.3 V USB-TTL adapter on `TX`/`RX` works as a fallback,
   but with `ARDUINO_USB_CDC_ON_BOOT=1` the serial log only appears on USB.
3. Bench CAN against a USB-CAN adapter needs termination at both ends. Easiest:
   a 120 Ω resistor across CANH/CANL at the adapter end (or the adapter's own
   termination switch) and a second 120 Ω clipped across P3/P4 — no soldering on
   the board. RT1/RT2 (2 × 60.4 Ω) are the on-board alternative; if you fit them,
   remove them before the bike.
4. On the bike: the 60 Ω check across CAN H/CAN L with the ignition off, as in
   the firmware repo's FLASHING.md, before the board is connected.
5. Solder the four wires (through the relief holes first), the antenna pigtail,
   then coat. Measure the sleep current in series with 12 V and compare with the
   17 mA baseline in SLEEP.md.

## Three things to know about the BOM

1. **Crystal and load capacitors.** JLCPCB's 40 MHz 3225 crystal (YXC
   X322540MPB4SI) has CL = 15 pF, not ~10 pF like LilyGO's. Hence C10/C11 are
   22 pF, not 12 pF. Rated −40…+85 °C — the ESP32 module is the limit at 65 °C anyway.
2. **The input TVS is bidirectional** (SMBJ24CA). It cannot be placed backwards,
   and D1 handles reverse polarity. It still clamps load dump at ~39 V.
3. **L1 (Murata DLW43SH) does not tolerate hard potting.** Murata's spec §13.4:
   cure stress from resin can change the inductance or break the wire. Use
   conformal coating or soft silicone — not epoxy — over L1 and X1.

## Rev 1.1 notes

See [REVIEW-rev1.0.md](REVIEW-rev1.0.md) for the reasoning.

- **Module: N8 or N16R2 (85 °C) instead of N16R8.** The firmware's PlatformIO
  board (`esp32-s3-devkitc-1`) never enables PSRAM and uses 8 MB of flash, so the
  85 °C variants need no firmware change. Same footprint, same LCSC family.
- **Flash with the board off the bike**, or from a laptop on battery. There is
  no isolation: a mains-powered PC's USB ground meets the bike's ground through
  the board.
- **Measure the cranking dip** before freezing rev 1.1. UVLO releases at 6.5 V;
  a cold start below that reboots the board.
- Housekeeping done in the repository after the rev 1.0 order: the leftover
  `ACC_SENSE` label on IO1 removed; BOM text for the 22 µF 0805s corrected to
  25 V (the ordered part was always 25 V).

Candidate board changes, to take along when the bench gives a reason for a new
order: test pads for 3V3 and VIN_PROT on the back; RT1/RT2 as 1206 with room to
hand-solder; an unpopulated 1.27 mm header footprint instead of the pogo pads;
and, only if the cranking measurement shows reboots, a regulator with a lower
minimum input.

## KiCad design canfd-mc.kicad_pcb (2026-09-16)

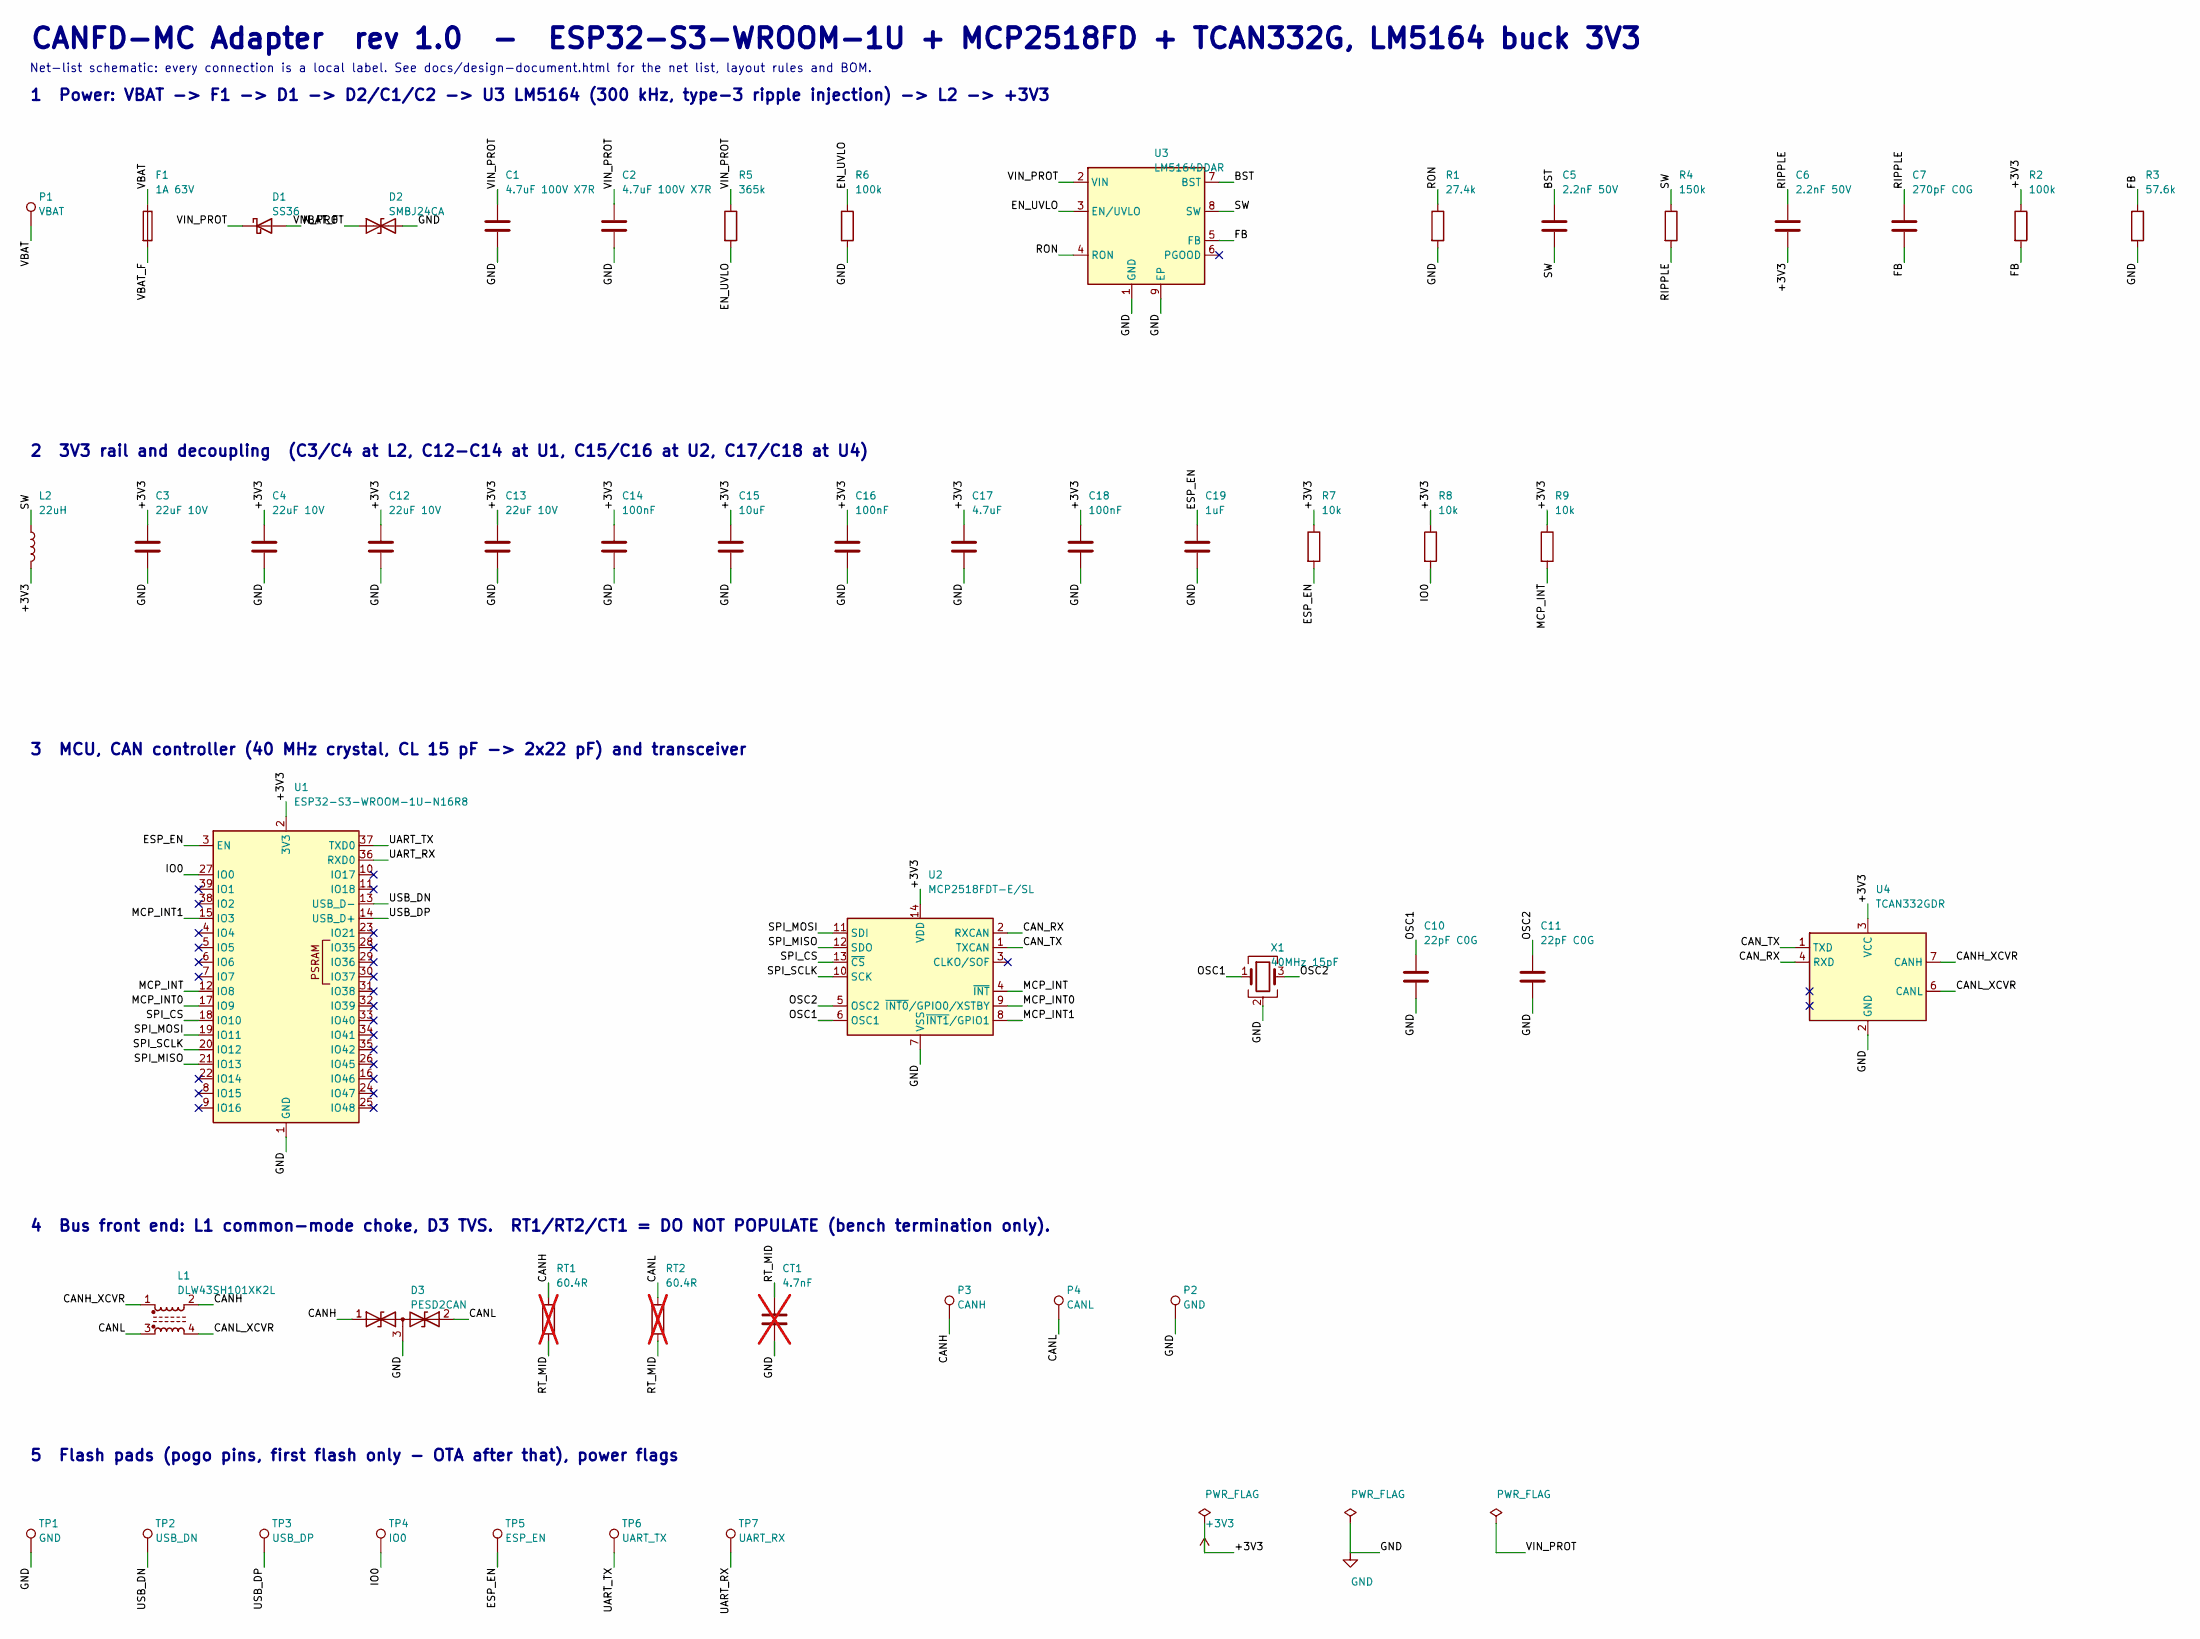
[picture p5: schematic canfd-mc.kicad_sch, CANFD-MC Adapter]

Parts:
C1, C2: 4.7uF 100V X7R; C_1210_3225Metric; LCSC C385986
C3, C4, C12, C13: 22uF 10V; C_0805_2012Metric; LCSC C45783
C5, C6: 2.2nF 50V; C_0603_1608Metric; LCSC C1604
C7: 270pF C0G; C_0603_1608Metric; LCSC C1657
C10, C11: 22pF C0G; C_0603_1608Metric; LCSC C1653
C14, C16, C18: 100nF; C_0603_1608Metric; LCSC C14663
C15: 10uF; C_0603_1608Metric; LCSC C19702
C17: 4.7uF; C_0603_1608Metric; LCSC C19666
C19: 1uF; C_0603_1608Metric; LCSC C15849
CT1: 4.7nF; C_0603_1608Metric; LCSC C53987; not fitted
D1: SS36; D_SMA; LCSC C16015
D2: SMBJ24CA; D_SMB; LCSC C83268
D3: PESD2CAN; SOT-23; LCSC C75176
F1: 1A 63V; Fuse_1206_3216Metric; LCSC C151135
L1: DLW43SH101XK2L; L_CommonModeChoke_Murata_DLW43SH; LCSC C123085
L2: 22uH; L_Changjiang_FNR5040S; LCSC C167971
P1: VBAT; SolderPad_D2.0mm_Relief
P2: GND; SolderPad_D2.0mm_Relief
P3: CANH; SolderPad_D1.5mm_Relief
P4: CANL; SolderPad_D1.5mm_Relief
R1: 27.4k; R_0603_1608Metric; LCSC C22964
R2, R6: 100k; R_0603_1608Metric; LCSC C25803
R3: 57.6k; R_0603_1608Metric; LCSC C23082
R4: 150k; R_0603_1608Metric; LCSC C22807
R5: 365k; R_0603_1608Metric; LCSC C23031
R7, R8, R9: 10k; R_0603_1608Metric; LCSC C25804
RT1, RT2: 60.4R; R_0805_2012Metric; LCSC C72998; not fitted
TP1: GND; TestPoint_Pad_D1.5mm
TP2: USB_DN; TestPoint_Pad_D1.5mm
TP3: USB_DP; TestPoint_Pad_D1.5mm
TP4: IO0; TestPoint_Pad_D1.5mm
TP5: ESP_EN; TestPoint_Pad_D1.5mm
TP6: UART_TX; TestPoint_Pad_D1.5mm
TP7: UART_RX; TestPoint_Pad_D1.5mm
U1: ESP32-S3-WROOM-1U-N16R8; ESP32-S3-WROOM-1U; LCSC C3013946
U2: MCP2518FDT-E/SL; SOIC-14_3.9x8.7mm_P1.27mm; LCSC C626758
U3: LM5164DDAR; TI_SO-PowerPAD-8_ThermalVias; LCSC C477928
U4: TCAN332GDR; SOIC-8_3.9x4.9mm_P1.27mm; LCSC C191010
X1: 40MHz 15pF; Crystal_SMD_3225-4Pin_3.2x2.5mm; LCSC C9010

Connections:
+3V3: C3.1, C4.1, C6.2, C12.1, C13.1, C14.1, C15.1, C16.1, C17.1, C18.1, L2.2, R2.1, R7.1, R8.1, R9.1, U1.2 (3V3), U2.14 (VDD), U4.3 (VCC)
/BST: C5.1, U3.7 (BST)
/CANH: D3.1 (A1), L1.2, P3.1 (1_1), RT1.1
/CANH_XCVR: L1.1, U4.7 (CANH)
/CANL: D3.2 (A2), L1.3, P4.1 (1_1), RT2.1
/CANL_XCVR: L1.4, U4.6 (CANL)
/CAN_RX: U2.2 (RXCAN), U4.4 (RXD)
/CAN_TX: U2.1 (TXCAN), U4.1 (TXD)
/EN_UVLO: R5.2, R6.1, U3.3 (EN/UVLO)
/ESP_EN: C19.1, R7.2, TP5.1 (1_1), U1.3 (EN)
/FB: C7.2, R2.2, R3.1, U3.5 (FB)
/IO0: R8.2, TP4.1 (1_1), U1.27 (IO0)
/MCP_INT: R9.2, U1.12 (IO8), U2.4 (~INT)
/MCP_INT0: U1.17 (IO9), U2.9 (~INT0/GPIO0/XSTBY)
/MCP_INT1: U1.15 (IO3), U2.8 (~INT1/GPIO1)
/OSC1: C10.1, U2.6 (OSC1), X1.1
/OSC2: C11.1, U2.5 (OSC2), X1.3
/RIPPLE: C6.1, C7.1, R4.2
/RON: R1.1, U3.4 (RON)
/RT_MID: CT1.1, RT1.2, RT2.2
/SPI_CS: U1.18 (IO10), U2.13 (~CS)
/SPI_MISO: U1.21 (IO13), U2.12 (SDO)
/SPI_MOSI: U1.19 (IO11), U2.11 (SDI)
/SPI_SCLK: U1.20 (IO12), U2.10 (SCK)
/SW: C5.2, L2.1, R4.1, U3.8 (SW)
/UART_RX: TP7.1 (1_1), U1.36 (RXD0)
/UART_TX: TP6.1 (1_1), U1.37 (TXD0)
/USB_DN: TP2.1 (1_1), U1.13 (USB_D-)
/USB_DP: TP3.1 (1_1), U1.14 (USB_D+)
/VBAT: F1.1, P1.1 (1_1)
/VBAT_F: D1.2 (A), F1.2
/VIN_PROT: C1.1, C2.1, D1.1 (K), D2.1 (A1), R5.1, U3.2 (VIN)
GND: C1.2, C2.2, C3.2, C4.2, C10.2, C11.2, C12.2, C13.2, C14.2, C15.2, C16.2, C17.2, C18.2, C19.2, CT1.2, D2.2 (A2), D3.3 (common), P2.1 (1_1), R1.2, R3.2, R6.2, TP1.1 (1_1), U1.1 (GND), U1.40 (GND), U1.41 (GND), U2.7 (VSS), U3.1 (GND), U3.9 (EP), U4.2 (GND), X1.2 (G), X1.4 (G)

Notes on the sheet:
CANFD-MC Adapter rev 1.0 - ESP32-S3-WROOM-1U + MCP2518FD + TCAN332G, LM5164 buck 3V3
Net-list schematic: every connection is a local label. See docs/design-document.html for the net list, layout rules and BOM.
1 Power: VBAT -> F1 -> D1 -> D2/C1/C2 -> U3 LM5164 (300 kHz, type-3 ripple injection) -> L2 -> +3V3
2 3V3 rail and decoupling (C3/C4 at L2, C12-C14 at U1, C15/C16 at U2, C17/C18 at U4)
3 MCU, CAN controller (40 MHz crystal, CL 15 pF -> 2x22 pF) and transceiver
4 Bus front end: L1 common-mode choke, D3 TVS. RT1/RT2/CT1 = DO NOT POPULATE (bench termination only).
5 Flash pads (pogo pins, first flash only - OTA after that), power flags

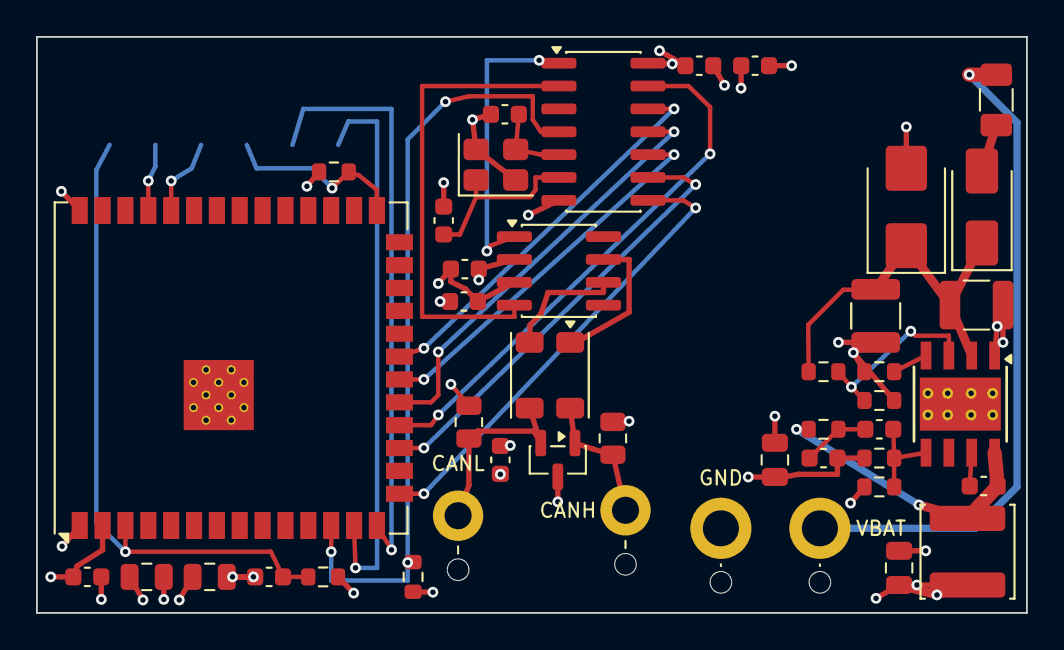
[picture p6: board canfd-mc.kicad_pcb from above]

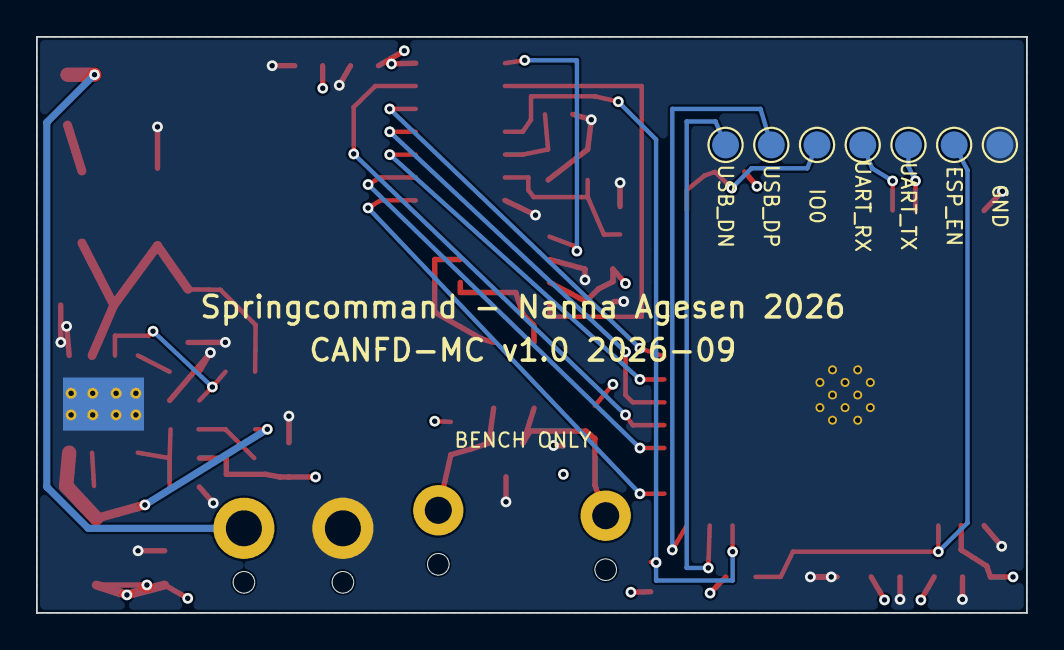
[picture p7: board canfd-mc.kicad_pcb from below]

Board: 4 copper layers, 55.0 x 32.0 mm, 51 parts (7 on the bottom side), 33 nets.

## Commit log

2026-09-15 CANFD-MC rev 1.0: KiCad project, production files, design document
    ESP32-S3-WROOM-1U + MCP2518FD + TCAN332G on 55x32 mm, 4 layers, LM5164
    buck from the bike's 12 V. Same pin map as the LilyGO T-2CANFD, so the
    indian-thunderstroke-canbus firmware runs unchanged. Placed, routed,
    DRC clean; ordered from JLCPCB in September 2026.
    [canfd-mc-BOM-JLCPCB.csv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]
2026-09-15 Review of rev 1.0: net list checked against the datasheets, three notes for rev 1.1, and an opinion on the design decisions
    The net list from the fabricated .kicad_pcb matches the firmware pin map
    and the WROOM-1U and LM5164 datasheets on every pin. For rev 1.1: the
    firmware build has no PSRAM, so an 85 C module needs no firmware change;
    a leftover single-pad net ACC_SENSE on IO1; the BOM comment says 10 V for
    a 25 V part. The minimal, unisolated, soldered, single-channel design is
    the right one for a permanently installed device on a motorcycle; the
    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
2026-09-16 Act on the rev 1.0 review
    Remove the leftover ACC_SENSE label on IO1 (schematic and board net);
    correct the 22 uF 0805 value text to 25 V, which is the part that was
    ordered; close the module open point now that the review found the
    firmware never enables PSRAM (rev 1.1: N8 or N16R2, 85 C, no firmware
    change); add the rev 1.1 notes to the design document and build notes.
    ERC 0, DRC 0, schematic and board nets match.
    [canfd-mc-BOM-JLCPCB.csv, canfd-mc.kicad_pcb]
2026-09-16 Rev 1.1 candidate board changes, for when the bench gives a reason
2026-09-16 Bench termination without touching the board
2026-09-16 Wiring parts: the antenna and the GT 150 service-connector cable
2026-09-16 3D renders of the board for the README (module shown as a stand-in box; KiCad has no WROOM-1U model)
2026-09-16 README: show the back of the board too
2026-09-16 Privacy policy for the Springfield app, hosted here until the app repo has a public page
